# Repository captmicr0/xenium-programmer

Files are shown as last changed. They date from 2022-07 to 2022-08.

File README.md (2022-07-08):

# OpenXenium JTAG and Flash Memory programmer
New smaller size board is less wasteful and has on-board buttons that actually work with the new script!  
LEDs are connected to different GPIOs than the original board, so **the old script will not work properly**.  
Plug the RPI and the OpenXenium modchip into their respective headers, and run the new script.  
The DETECT LED below the OpenXenium outline will turn on when a modchip is inserted.

### Raspberry PI:
- This has only been tested on PI Zero W so far.

-------------
## INSTALLING THE XENIUM PROGRAMMER

On the PI:
- Clone this repo by running: `git clone https://github.com/captmicr0/xenium-programmer`
- Then run: `./install`

## UPDATING XENIUM PROGRAMMER

On the PI:
- Pull the latest code with: `git pull`
- Then run: `./install` 

-------------
## PROGRAMMING A XENIUM CPLD AND FLASH MEMORY

- Connect to the PI or Omega via SSH or Serial terminal
- Run: `./xenium-programmer-small`
- On the board, press the BIOS button to write a new BIOS to the OpenXenium flash chip
- On the board, press the CPLD button to program the Xilinx CPLD on the OpenXenium.

**Note**: Pressing the BIOS button will flash a program onto the CPLD that allows you to  
write to the flash chip. This overwrites the OpenXenium firmware, so you must re-program  
the CPLD afterwards by pressing the CPLD button.

### SMALL PC BOARD

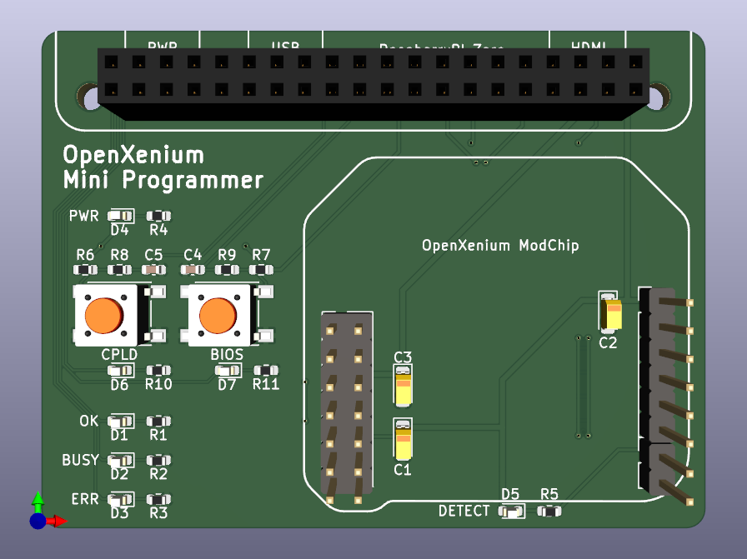
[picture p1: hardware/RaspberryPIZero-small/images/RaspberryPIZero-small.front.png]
RPI PXB


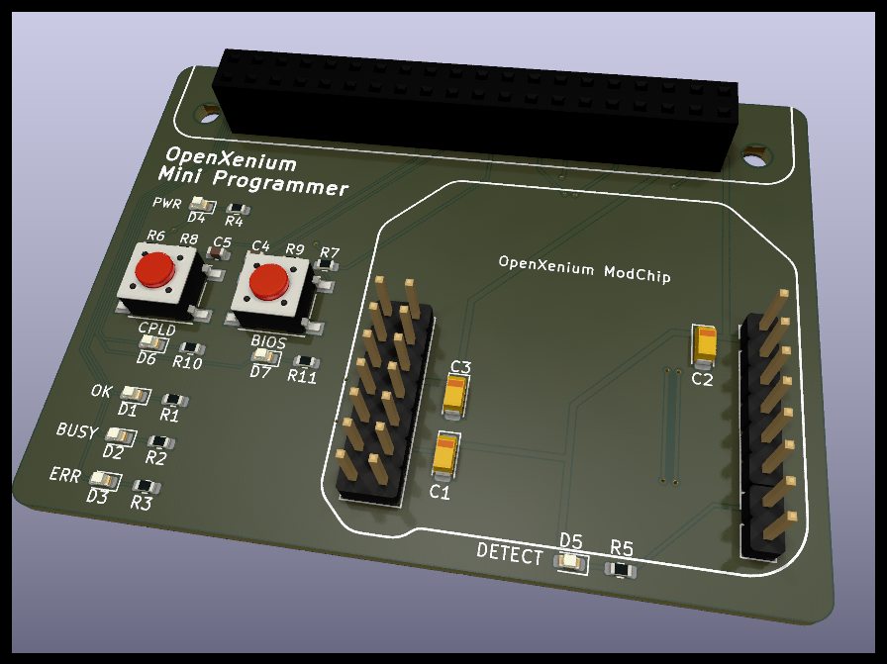
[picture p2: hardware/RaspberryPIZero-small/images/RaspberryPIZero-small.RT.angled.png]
RPI PXC


-------------
## CREDITS

- Koos du Preez - Creator (kdupreez@hotmail.com - Comments, improvements, critique, etc. is welcome!)
- James Bolding - Kick ass awesome hardware design and PCB!
- captmicr0 - Smaller board design and modified script for it.
- Ryzee119 -  OpenXenium Firmware and hardware and all round awesomeness!
- XC3SPROG - Not sure who to thank here, but the source code was pivotal in making this work!

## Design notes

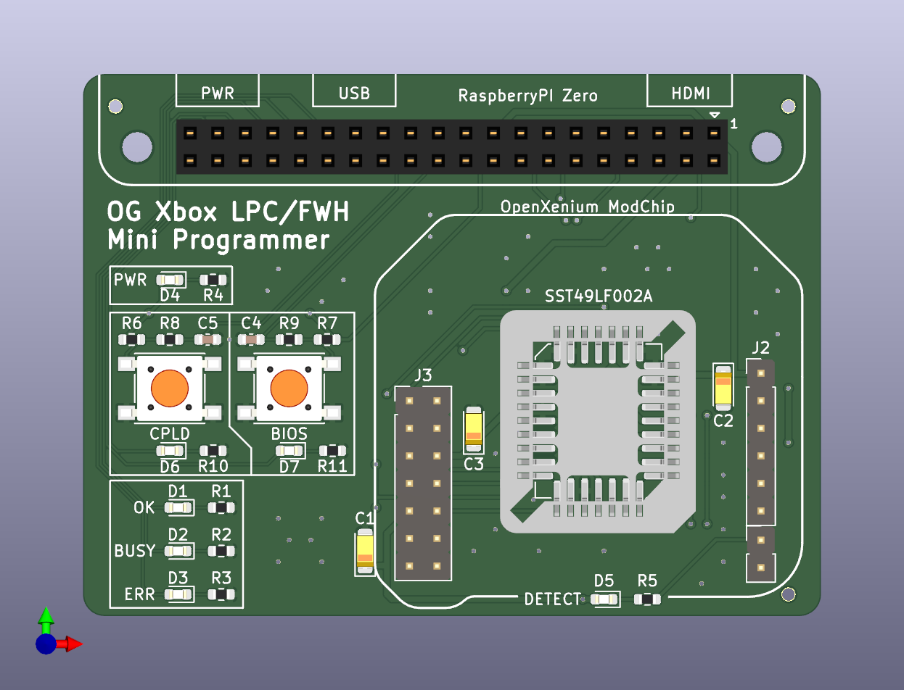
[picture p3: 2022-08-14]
hardware/RaspberryPIZero-small/images/RaspberryPIZero-small.top.png

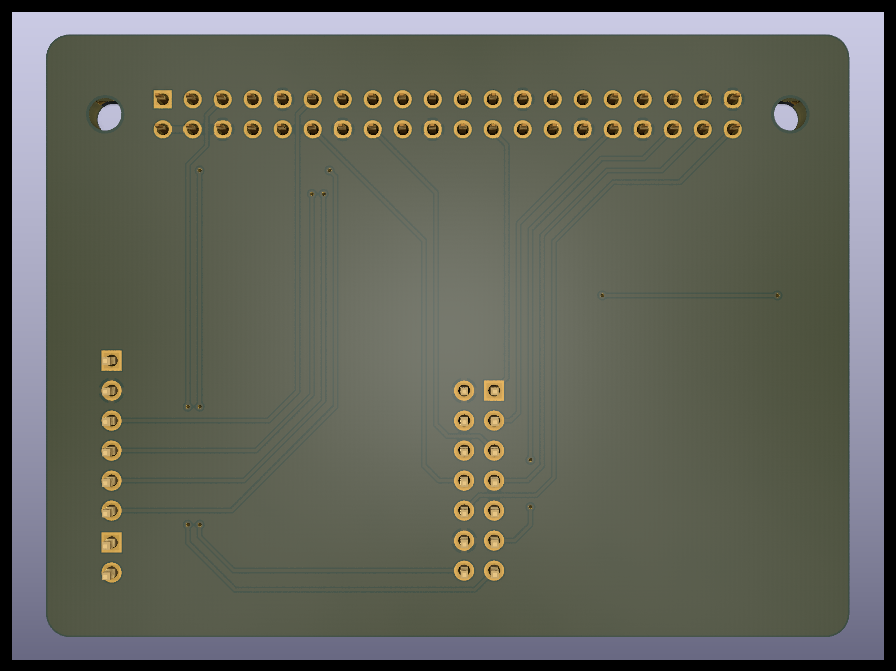
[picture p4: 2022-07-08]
hardware/RaspberryPIZero-small/images/RaspberryPIZero-small.RT.back.png

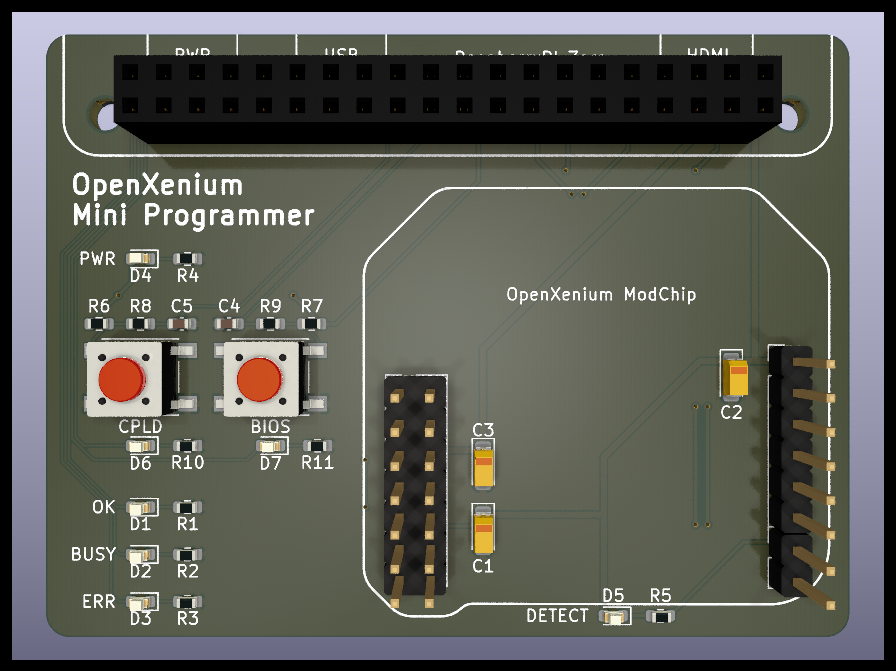
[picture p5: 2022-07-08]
hardware/RaspberryPIZero-small/images/RaspberryPIZero-small.RT.front.png

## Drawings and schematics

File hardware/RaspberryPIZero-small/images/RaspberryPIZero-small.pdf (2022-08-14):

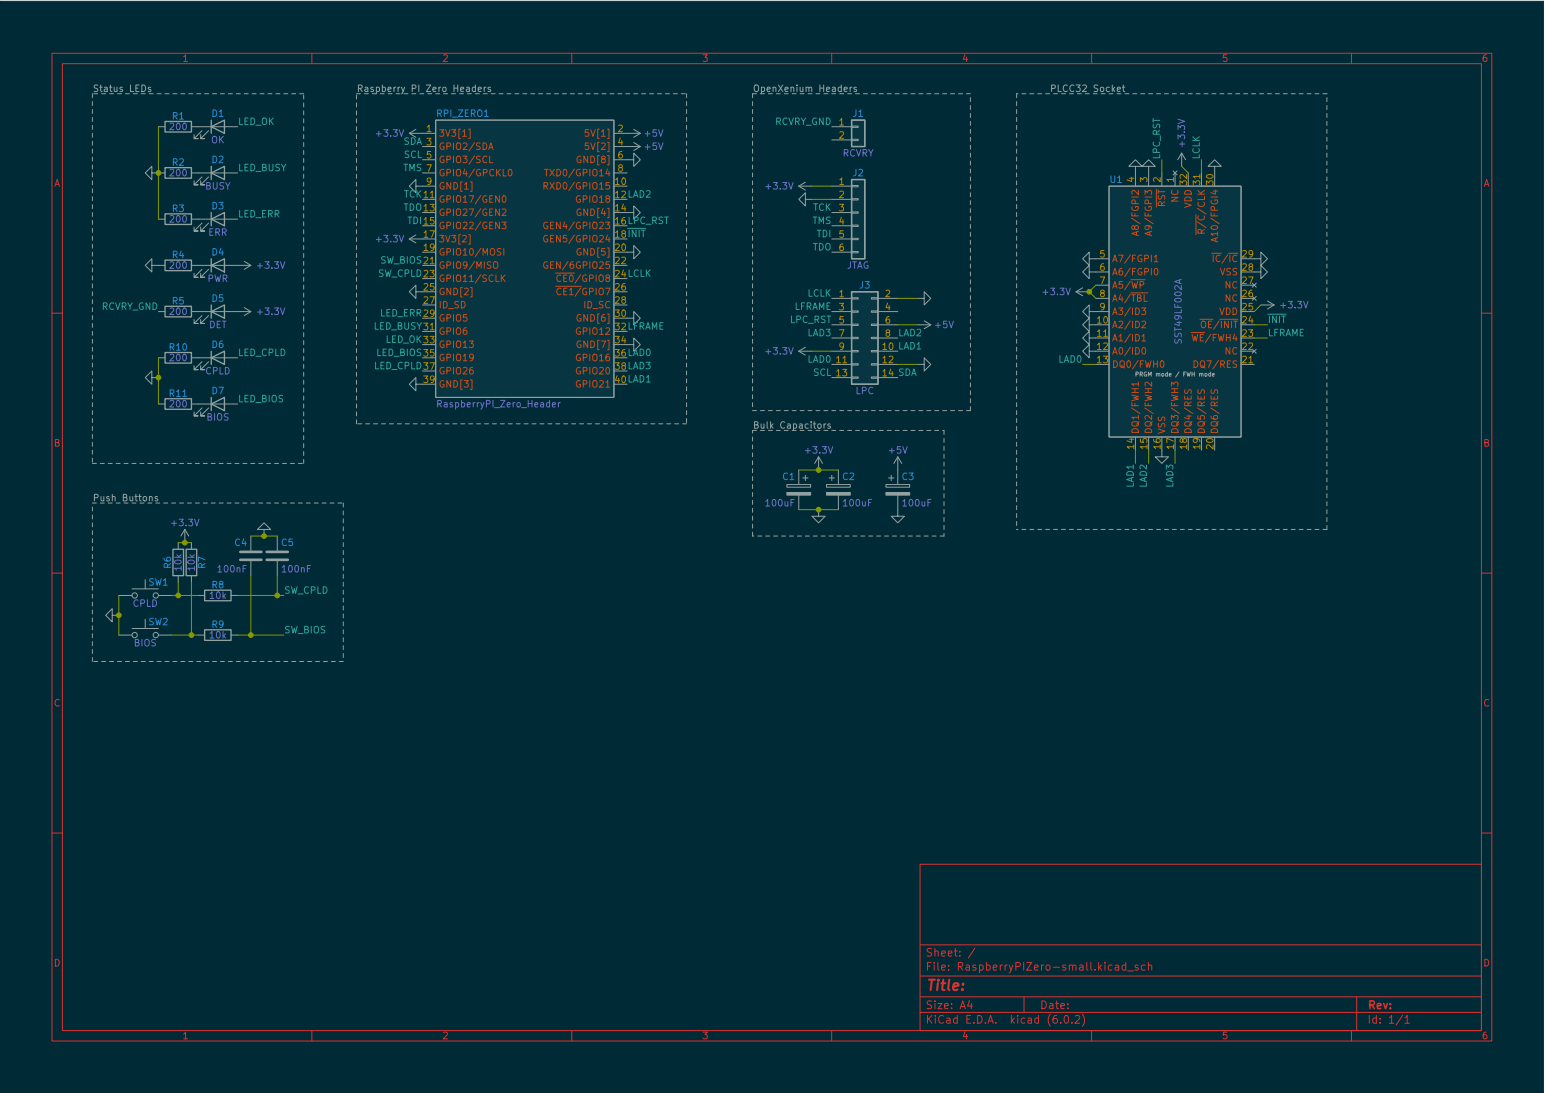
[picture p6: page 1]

PRGM mode / FWH mode NC

1 A2/ID2 10 A1/ID1 11 A0/ID0 12 DQ0/FWH0 13 DQ1/FWH1 14 DQ2/FWH2 15 VSS 16 DQ3/FWH3 17 DQ4/RES 18 DQ5/RES 19 ~{RST} 2 DQ6/RES 20 DQ7/RES 21 NC 22 ~{WE}/FWH423 ~{OE}/~{INIT}24 VDD 25 NC 26 NC 27 VSS 28 ~{IC}/~{IC}29 A9/FGPI3

File: RaspberryPIZero-small.kicad_sch Sheet: /
Id: 1/1 Title:

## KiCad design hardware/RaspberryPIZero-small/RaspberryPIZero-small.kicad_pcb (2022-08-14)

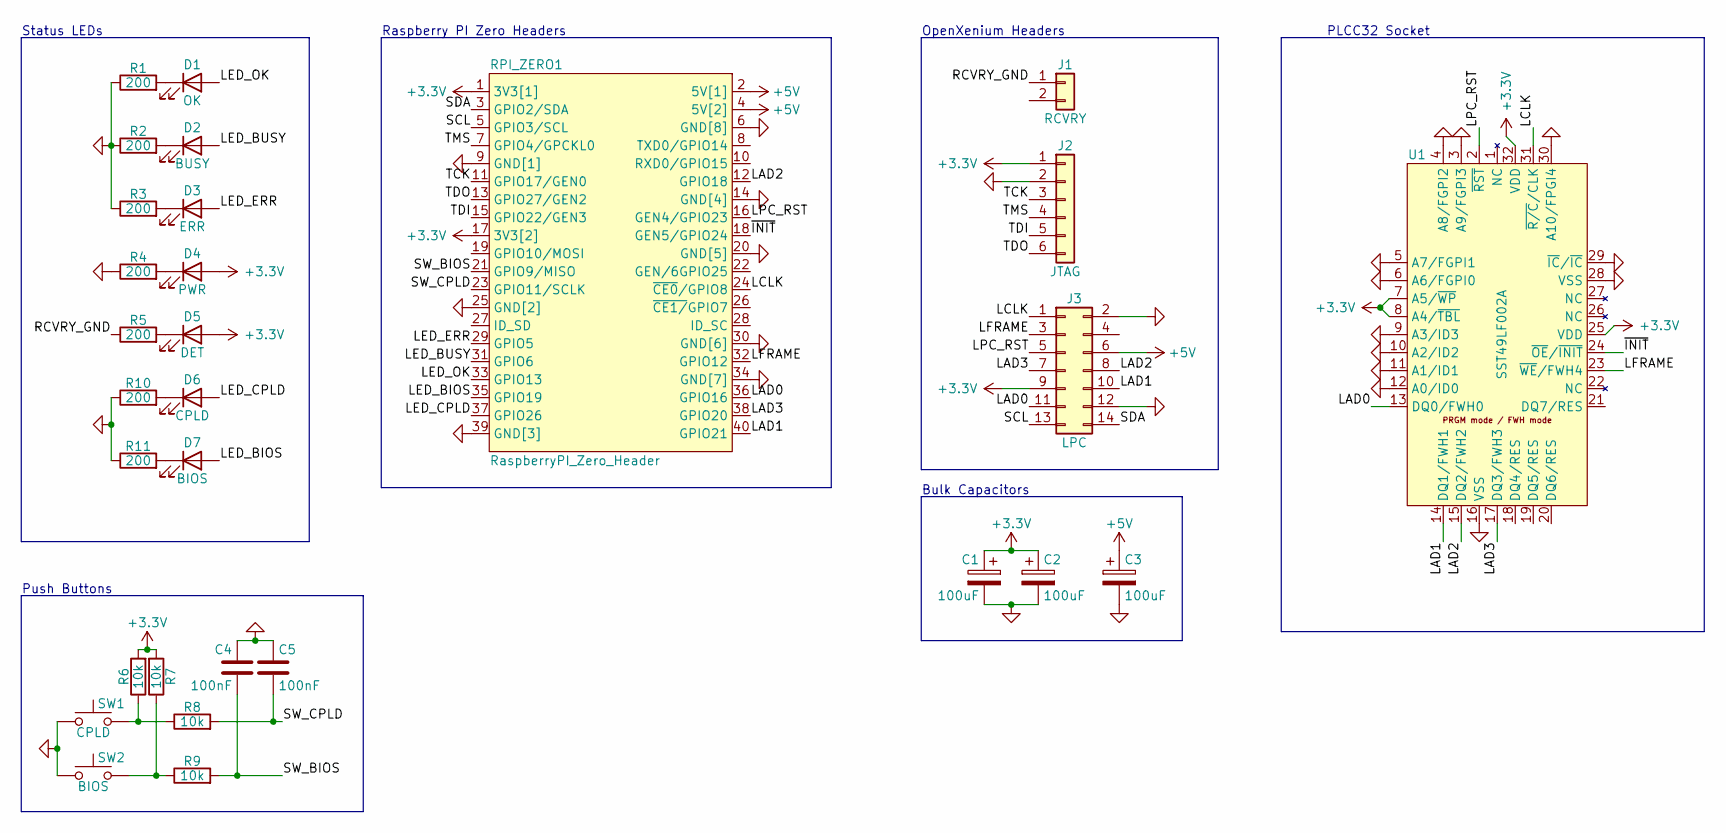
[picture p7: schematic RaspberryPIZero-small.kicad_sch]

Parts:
C1, C2, C3: 100uF; CP_EIA-3216-18_Kemet-A; MFR# CL31A107MQHNNNE; LCSC# C15008
C4, C5: 100nF; C_0603_1608Metric; MFR# CC0603KRX7R9BB104; LCSC# C14663
D1: OK; LED_0603_1608Metric; MFR# SZYY0603G; LCSC# C434420
D2: BUSY; LED_0603_1608Metric; MFR# SZYY0603O; LCSC# C434425
D3: ERR; LED_0603_1608Metric; MFR# SZYY0603R; LCSC# C434419
D4: PWR; LED_0603_1608Metric; MFR# SZYY0603B; LCSC# C434421
D5: DET; LED_0603_1608Metric; MFR# SZYY0603B; LCSC# C434421
D6: CPLD; LED_0603_1608Metric; MFR# SZYY0603O; LCSC# C434425
D7: BIOS; LED_0603_1608Metric; MFR# SZYY0603O; LCSC# C434425
J1: RCVRY; PinHeader_1x02_P2.54mm_Vertical
J2: JTAG; PinHeader_1x06_P2.54mm_Vertical; MFR# C2337; LCSC# C2337
J3: LPC; PinHeader_2x07_P2.54mm_Vertical; MFR# C57369; LCSC# C57369
R1, R2, R3, R4, R5, R10, R11: 200; R_0603_1608Metric; MFR# 0603WAF2000T5E; LCSC# C8218
R6, R7, R8, R9: 10k; R_0603_1608Metric; MFR# 0603WAF1002T5E; LCSC# C25804
RPI_ZERO1: RaspberryPI_Zero_Header; RaspberryPI_Zero; MFR# X6521FV-2x10-C85D32; LCSC# C718226
SW1: CPLD; SW_SPST_PTS645; MFR# PTS645SM70SMTR92LFS; LCSC# C221883
SW2: BIOS; SW_SPST_PTS645; MFR# PTS645SM70SMTR92LFS; LCSC# C221883
U1: SST49LF002A; PLCC-32-SOCKET-SMT

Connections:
+3V3: C1.1, C2.1, D4.2 (A), D5.2 (A), J2.1, J3.9, R6.2, R7.2, RPI_ZERO1.1 (3V3[1]), RPI_ZERO1.17 (3V3[2]), U1.7 (A5/~WP), U1.8 (A4/~TBL), U1.25 (VDD), U1.32 (VDD)
+5V: C3.1, J3.6, RPI_ZERO1.2 (5V[1]), RPI_ZERO1.4 (5V[2])
/LAD0: J3.11, RPI_ZERO1.36 (GPIO16), U1.13 (DQ0/FWH0)
/LAD1: J3.10, RPI_ZERO1.40 (GPIO21), U1.14 (DQ1/FWH1)
/LAD2: J3.8, RPI_ZERO1.12 (GPIO18), U1.15 (DQ2/FWH2)
/LAD3: J3.7, RPI_ZERO1.38 (GPIO20), U1.17 (DQ3/FWH3)
/LCLK: J3.1, RPI_ZERO1.24 (~CE0/GPIO8), U1.31 (~R/C/CLK)
/LED_BIOS: D7.2 (A), RPI_ZERO1.35 (GPIO19)
/LED_BUSY: D2.2 (A), RPI_ZERO1.31 (GPIO6)
/LED_CPLD: D6.2 (A), RPI_ZERO1.37 (GPIO26)
/LED_ERR: D3.2 (A), RPI_ZERO1.29 (GPIO5)
/LED_OK: D1.2 (A), RPI_ZERO1.33 (GPIO13)
/LFRAME: J3.3, RPI_ZERO1.32 (GPIO12), U1.23 (~WE/FWH4)
/LPC_RST: J3.5, RPI_ZERO1.16 (GEN4/GPIO23), U1.2 (~RST)
/RCVRY_GND: J1.1, R5.1
/SCL: J3.13, RPI_ZERO1.5 (GPIO3/SCL)
/SDA: J3.14, RPI_ZERO1.3 (GPIO2/SDA)
/SW_BIOS: C4.2, R9.2, RPI_ZERO1.21 (GPIO9/MISO)
/SW_CPLD: C5.2, R8.2, RPI_ZERO1.23 (GPIO11/SCLK)
/TCK: J2.3, RPI_ZERO1.11 (GPIO17/GEN0)
/TDI: J2.5, RPI_ZERO1.15 (GPIO22/GEN3)
/TDO: J2.6, RPI_ZERO1.13 (GPIO27/GEN2)
/TMS: J2.4, RPI_ZERO1.7 (GPIO4/GPCKL0)
/~INIT: RPI_ZERO1.18 (GEN5/GPIO24), U1.24 (~OE/~INIT)
GND: C1.2, C2.2, C3.2, C4.1, C5.1, J2.2, J3.2, J3.12, R1.1, R2.1, R3.1, R4.1, R10.1, R11.1, RPI_ZERO1.6 (GND[8]), RPI_ZERO1.9 (GND[1]), RPI_ZERO1.14 (GND[4]), RPI_ZERO1.20 (GND[5]), RPI_ZERO1.25 (GND[2]), RPI_ZERO1.30 (GND[6]), RPI_ZERO1.34 (GND[7]), RPI_ZERO1.39 (GND[3]), SW1.1, SW2.1, U1.3 (A9/FGPI3), U1.4 (A8/FGPI2), U1.5 (A7/FGPI1), U1.6 (A6/FGPI0), U1.9 (A3/ID3), U1.10 (A2/ID2), U1.11 (A1/ID1), U1.12 (A0/ID0), U1.16 (VSS), U1.28 (VSS), U1.29 (~IC/~IC), U1.30 (A10/FPGI4)
unnamed: D1.1 (K), R1.2
unnamed: D2.1 (K), R2.2
unnamed: D3.1 (K), R3.2
unnamed: D4.1 (K), R4.2
unnamed: D5.1 (K), R5.2
unnamed: D6.1 (K), R10.2
unnamed: D7.1 (K), R11.2
unnamed: R6.1, R8.1, SW1.2
unnamed: R7.1, R9.1, SW2.2

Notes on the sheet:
OpenXenium Headers
Bulk Capacitors
PLCC32 Socket
Status LEDs
Push Buttons
Raspberry PI Zero Headers

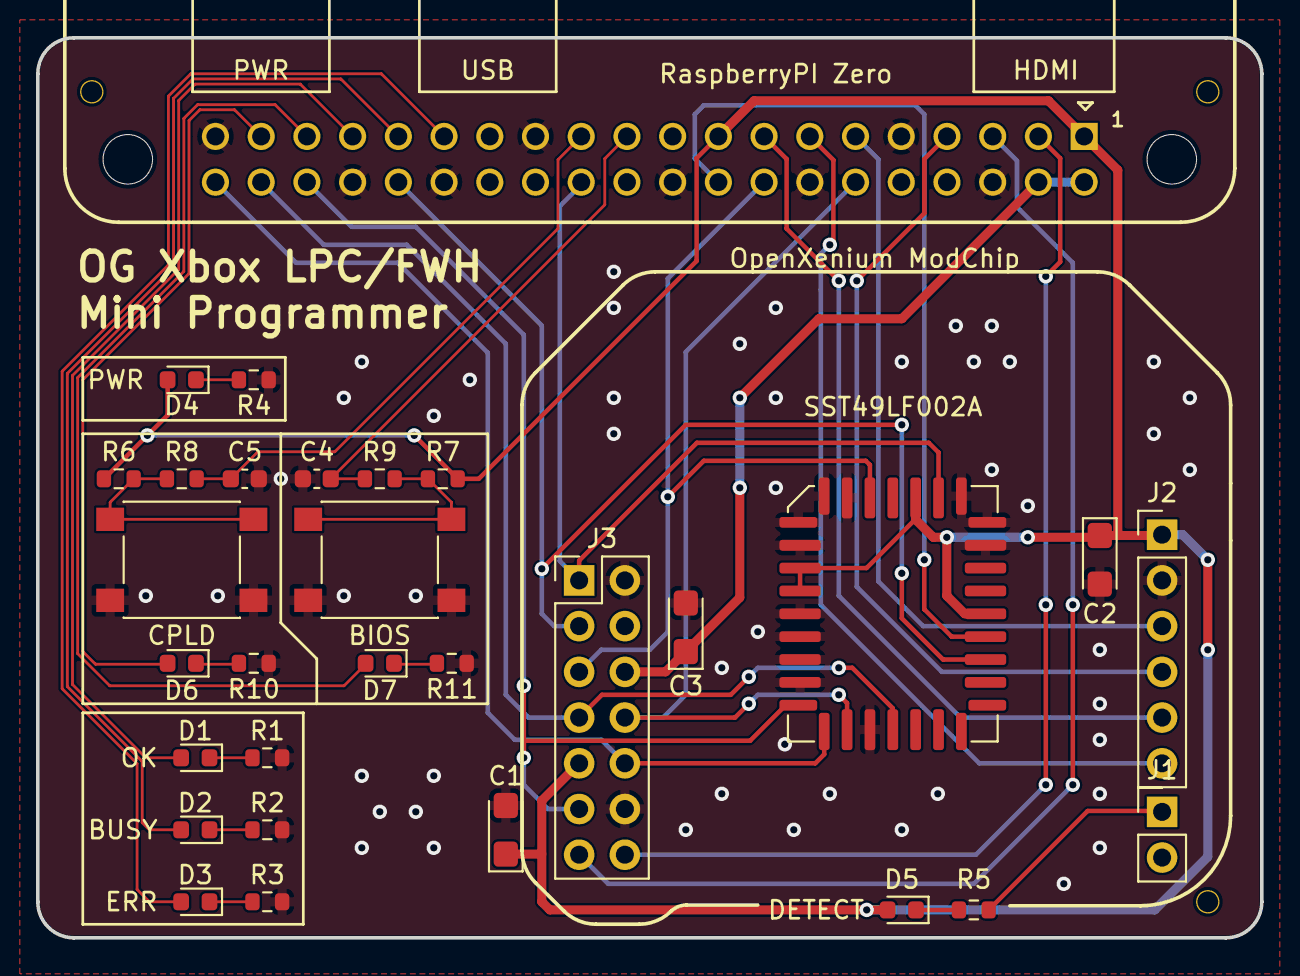
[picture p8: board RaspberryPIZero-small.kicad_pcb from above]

Board: 2 copper layers, 68.0 x 50.0 mm, 30 parts (0 on the bottom side), 34 nets.

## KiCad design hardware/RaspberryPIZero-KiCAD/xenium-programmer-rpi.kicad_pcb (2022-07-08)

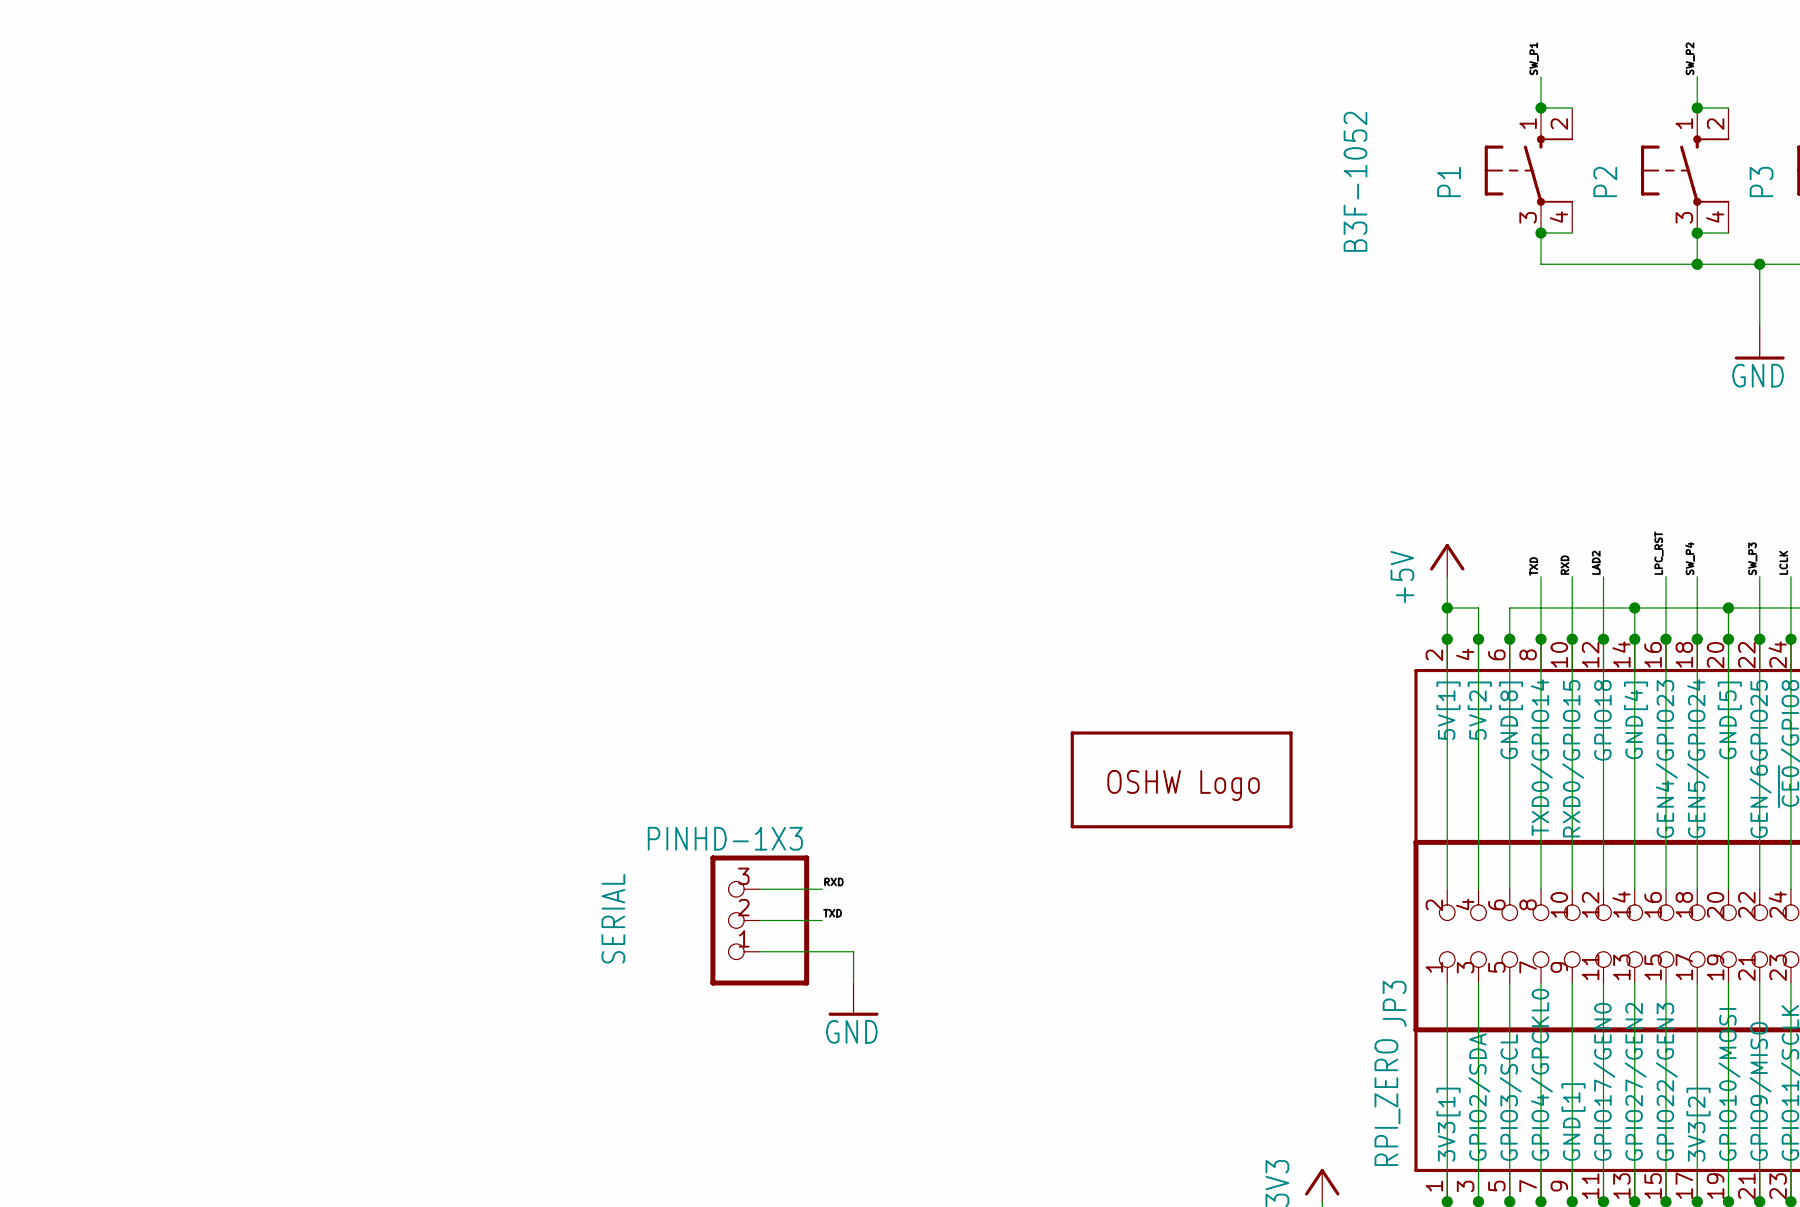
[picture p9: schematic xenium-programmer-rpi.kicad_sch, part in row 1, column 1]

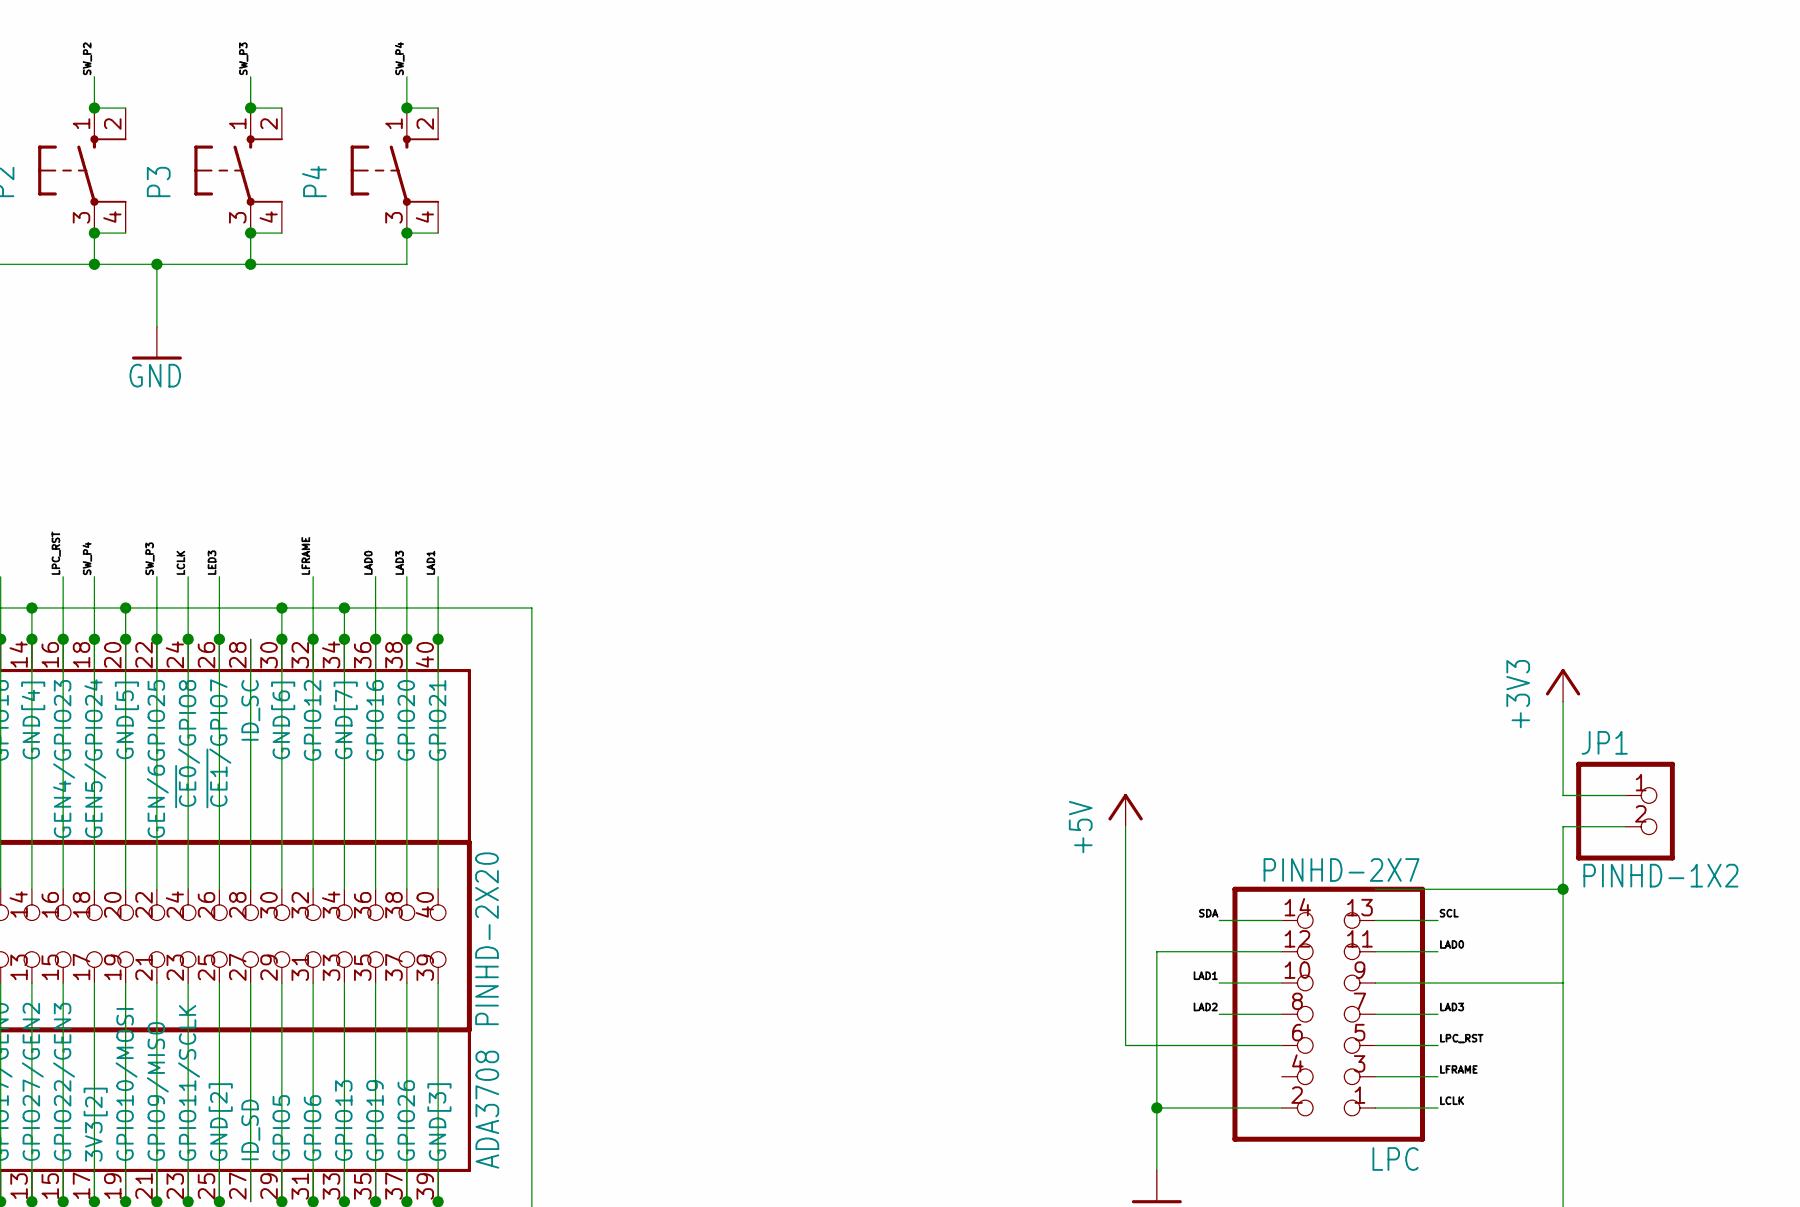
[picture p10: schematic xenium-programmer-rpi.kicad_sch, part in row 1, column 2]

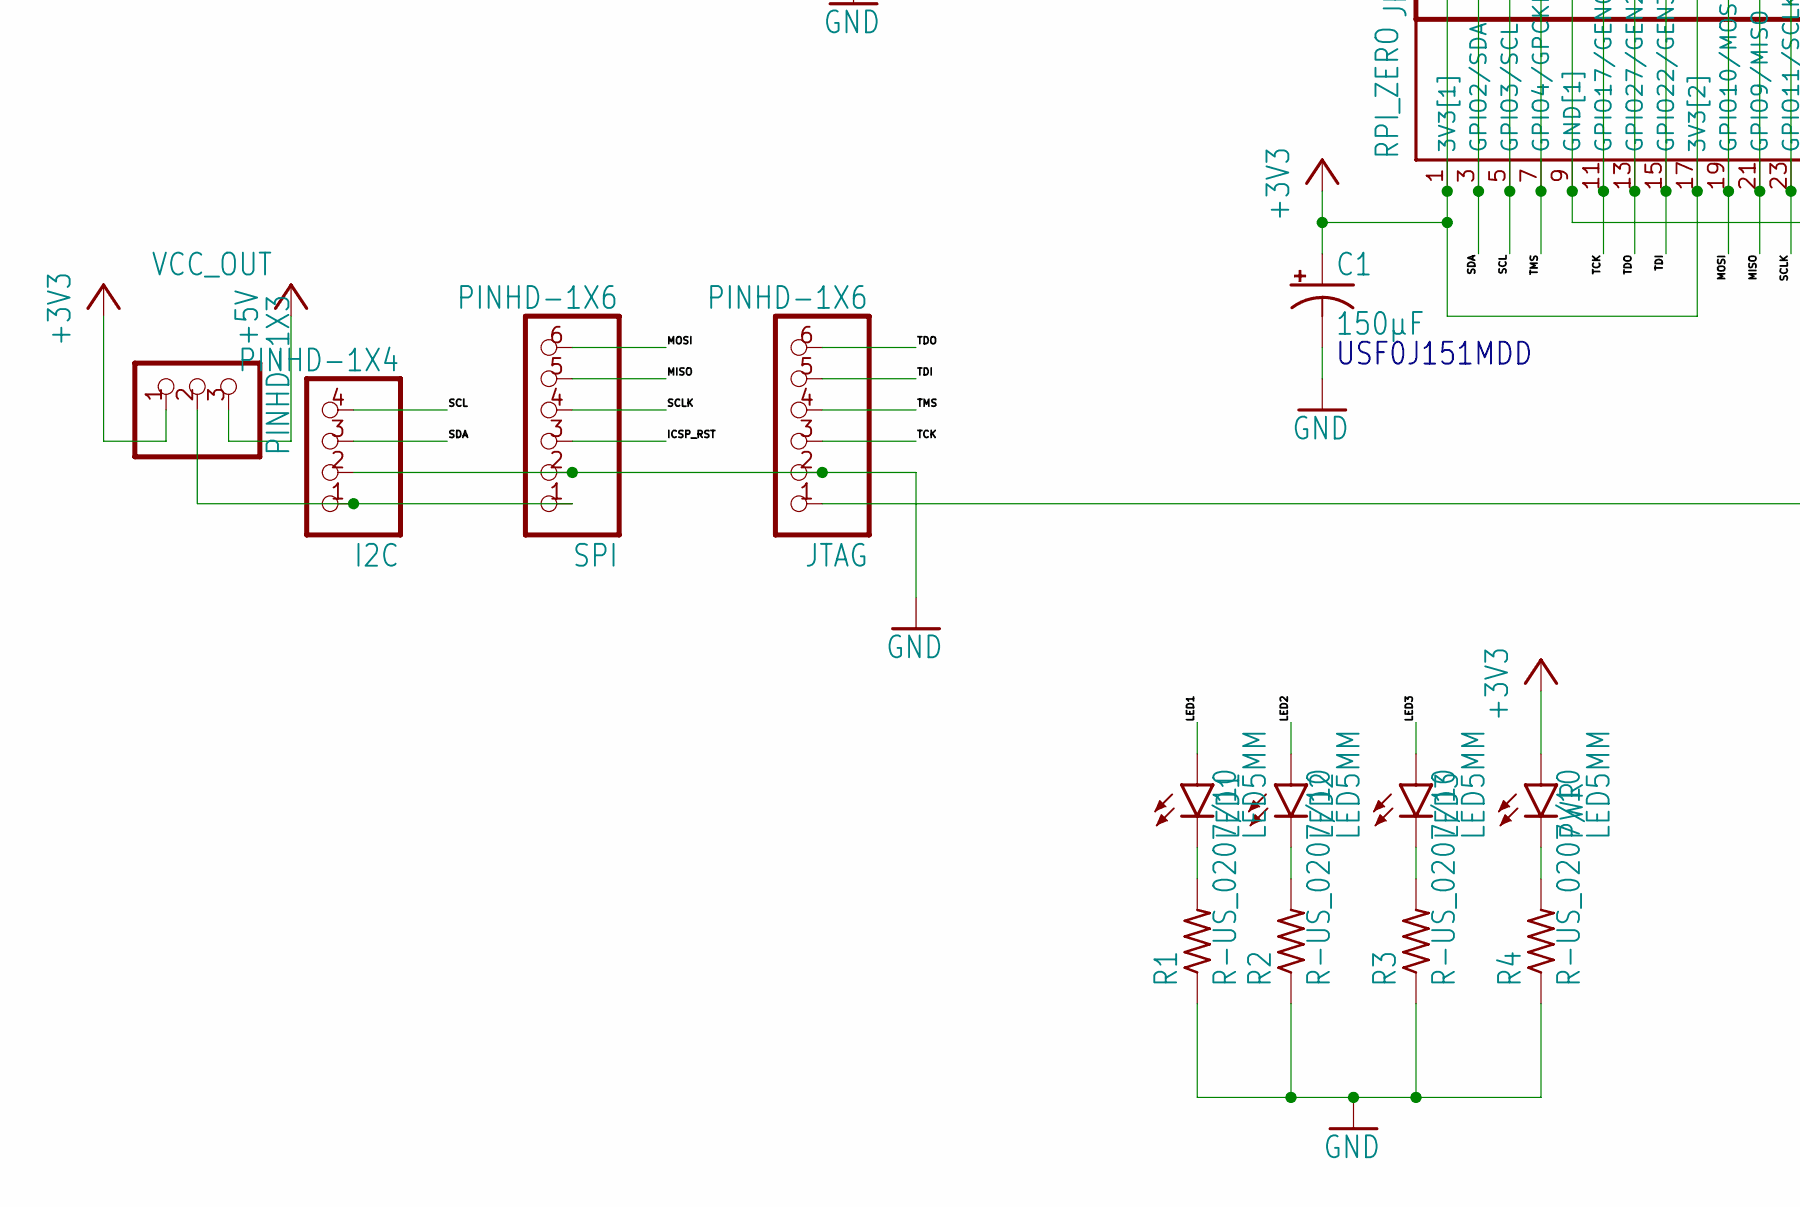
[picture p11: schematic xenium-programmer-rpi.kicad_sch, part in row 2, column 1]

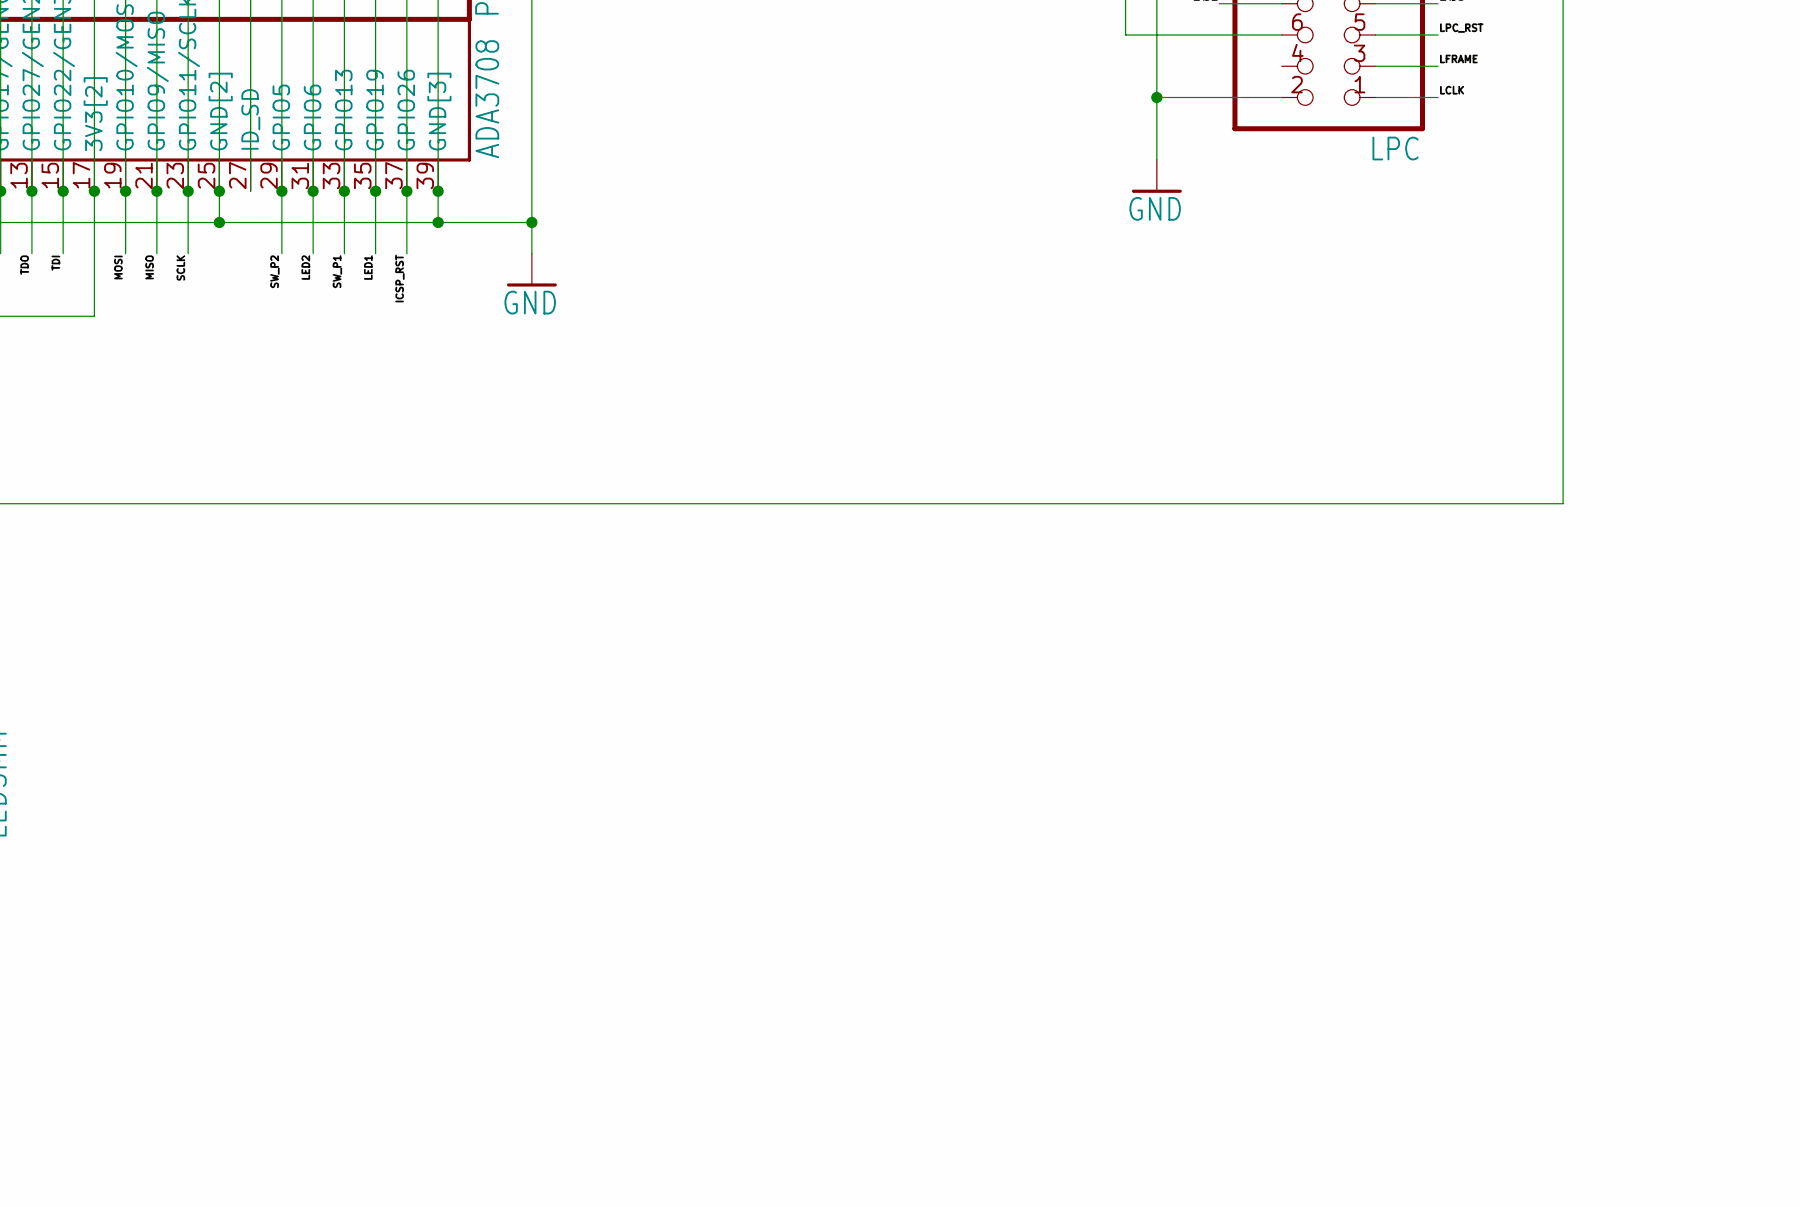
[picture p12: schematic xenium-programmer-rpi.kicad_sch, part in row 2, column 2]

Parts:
C1: 150µF; E3,5-8
GOLD_ORB_SM1: OSHWLOGOLOGO8MM; OSHW_8MM
I2C: PINHD-1X4; 1X04
JP1: PINHD-1X2; 1X02
JP3: PINHD-2X20; 2X20
JTAG: PINHD-1X6; 1X06
LED1, LED2, LED3: LED5MM
LPC: PINHD-2X7; 2X07
P1, P2, P3, P4: B3F-1052; B3F-10XX
PWR: LED5MM
R1, R2, R3, R4: R-US_0207/10; 0207_10
RPI_ZERO: ADA3708; ADA3708_RPI-ZERO
SERIAL: PINHD-1X3; 1X03
SPI: PINHD-1X6; 1X06
VCC_OUT: PINHD-1X3; 1X03

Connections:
+3V3: C1.+, JP1.1, JP3.1, JP3.17, PWR.A, RPI_ZERO.1 (3V3[1]), RPI_ZERO.17 (3V3[2]), VCC_OUT.1
+5V: JP3.2, JP3.4, LPC.6, RPI_ZERO.2 (5V[1]), RPI_ZERO.4 (5V[2]), VCC_OUT.3
GND: C1.-, I2C.2, JP3.6, JP3.9, JP3.14, JP3.20, JP3.25, JP3.30, JP3.34, JP3.39, JTAG.2, LPC.2, LPC.12, P1.3, P1.4 (P1), P2.3, P2.4 (P1), P3.3, P3.4 (P1), P4.3, P4.4 (P1), R1.1, R2.1, R3.1, R4.1, RPI_ZERO.6 (GND[8]), RPI_ZERO.9 (GND[1]), RPI_ZERO.14 (GND[4]), RPI_ZERO.20 (GND[5]), RPI_ZERO.25 (GND[2]), RPI_ZERO.30 (GND[6]), RPI_ZERO.34 (GND[7]), RPI_ZERO.39 (GND[3]), SERIAL.1, SPI.2
ICSP_RST: JP3.37, RPI_ZERO.37 (GPIO26), SPI.3
LAD0: JP3.36, LPC.11, RPI_ZERO.36 (GPIO16)
LAD1: JP3.40, LPC.10, RPI_ZERO.40 (GPIO21)
LAD2: JP3.12, LPC.8, RPI_ZERO.12 (GPIO18)
LAD3: JP3.38, LPC.7, RPI_ZERO.38 (GPIO20)
LCLK: JP3.24, LPC.1, RPI_ZERO.24 (~CE0/GPIO8)
LED1: JP3.35, LED1.A, RPI_ZERO.35 (GPIO19)
LED2: JP3.31, LED2.A, RPI_ZERO.31 (GPIO6)
LED3: JP3.26, LED3.A, RPI_ZERO.26 (~CE1/GPIO7)
LFRAME: JP3.32, LPC.3, RPI_ZERO.32 (GPIO12)
LPC_RST: JP3.16, LPC.5, RPI_ZERO.16 (GEN4/GPIO23)
MISO: JP3.21, RPI_ZERO.21 (GPIO9/MISO), SPI.5
MOSI: JP3.19, RPI_ZERO.19 (GPIO10/MOSI), SPI.6
unnamed: LED1.K (C), R1.2
unnamed: JP3.27, RPI_ZERO.27 (ID_SD)
unnamed: LED2.K (C), R2.2
unnamed: LED3.K (C), R3.2
unnamed: PWR.K (C), R4.2
unnamed: JP1.2, JTAG.1, LPC.9
unnamed: JP3.28, RPI_ZERO.28 (ID_SC)
RXD: JP3.10, RPI_ZERO.10 (RXD0/GPIO15), SERIAL.3
SCL: I2C.4, JP3.5, LPC.13, RPI_ZERO.5 (GPIO3/SCL)
SCLK: JP3.23, RPI_ZERO.23 (GPIO11/SCLK), SPI.4
SDA: I2C.3, JP3.3, LPC.14, RPI_ZERO.3 (GPIO2/SDA)
SW_P1: JP3.33, P1.1 (S), P1.2 (S1), RPI_ZERO.33 (GPIO13)
SW_P2: JP3.29, P2.1 (S), P2.2 (S1), RPI_ZERO.29 (GPIO5)
SW_P3: JP3.22, P3.1 (S), P3.2 (S1), RPI_ZERO.22 (GEN/6GPIO25)
SW_P4: JP3.18, P4.1 (S), P4.2 (S1), RPI_ZERO.18 (GEN5/GPIO24)
TCK: JP3.11, JTAG.3, RPI_ZERO.11 (GPIO17/GEN0)
TDI: JP3.15, JTAG.5, RPI_ZERO.15 (GPIO22/GEN3)
TDO: JP3.13, JTAG.6, RPI_ZERO.13 (GPIO27/GEN2)
TMS: JP3.7, JTAG.4, RPI_ZERO.7 (GPIO4/GPCKL0)
TXD: JP3.8, RPI_ZERO.8 (TXD0/GPIO14), SERIAL.2
VCC_OUT: I2C.1, SPI.1, VCC_OUT.2

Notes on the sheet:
USF0J151MDD

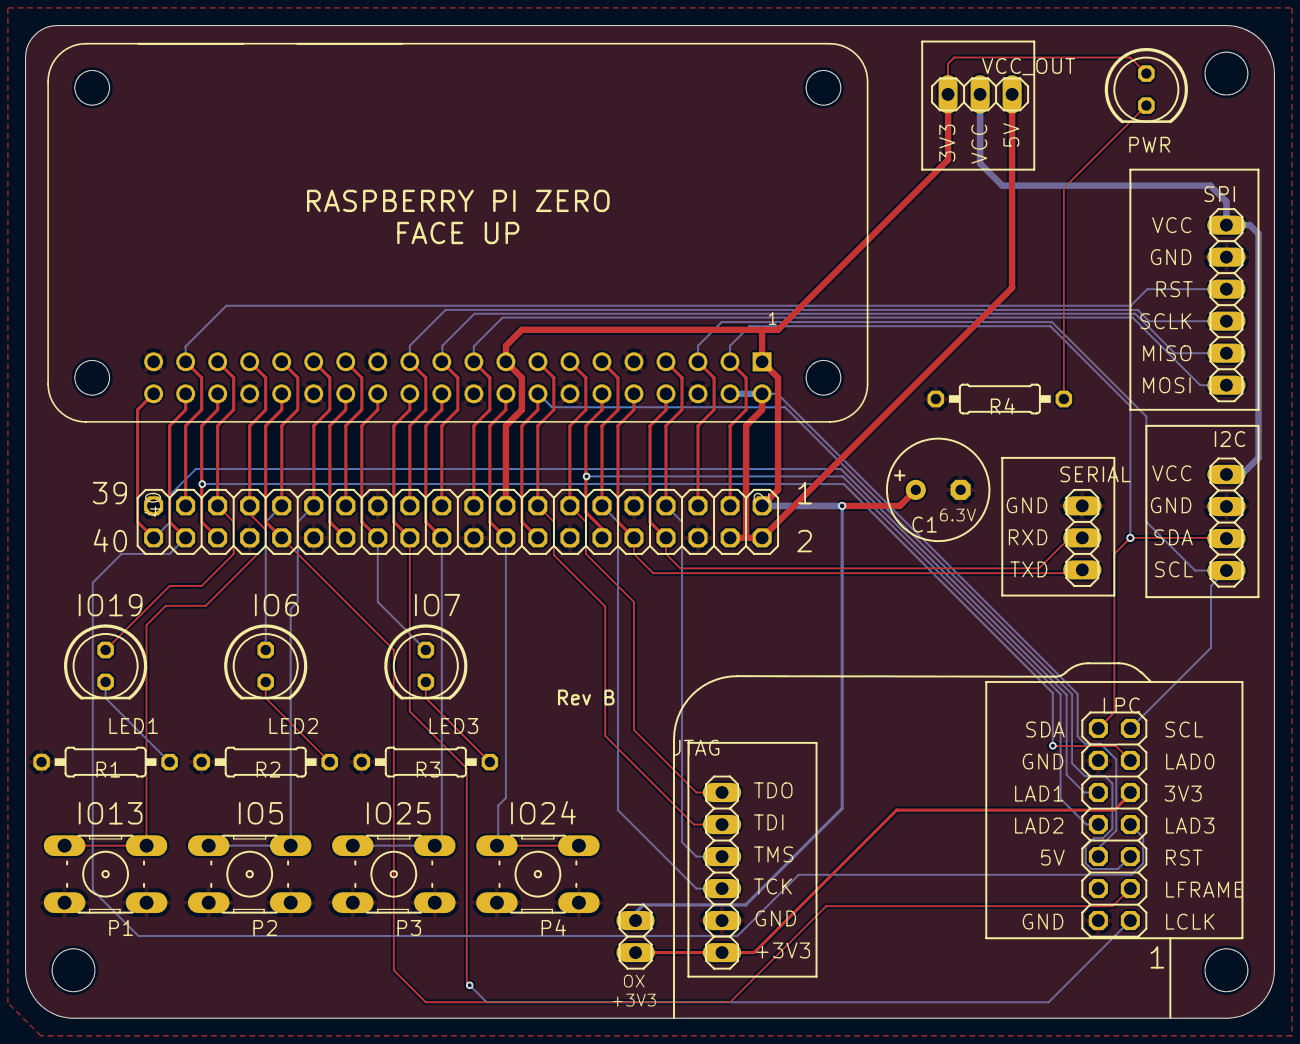
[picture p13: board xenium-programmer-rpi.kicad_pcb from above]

Board: 2 copper layers, 99.1 x 78.7 mm, 26 parts (1 on the bottom side), 37 nets.

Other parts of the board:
@HOLE0, @HOLE1, @HOLE2: (no value)

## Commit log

2022-07-08 converted to KiCAD, added SFF board, added script for SFF board
    [RaspberryPIZero-small-B_Cu.gbl, RaspberryPIZero-small-B_Mask.gbs, RaspberryPIZero-small-B_Paste.gbp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]
2022-07-08 added tooling holes to pcb & create JLCPCB manufacturing files
    [RaspberryPIZero-small-B_Cu.gbl, RaspberryPIZero-small-B_Mask.gbs, RaspberryPIZero-small-B_Paste.gbp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]
2022-08-14 modified board to support flashing 49LF002A
    [RaspberryPIZero-small-B_Cu.gbl, RaspberryPIZero-small-B_Mask.gbs, RaspberryPIZero-small-B_Paste.gbp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]

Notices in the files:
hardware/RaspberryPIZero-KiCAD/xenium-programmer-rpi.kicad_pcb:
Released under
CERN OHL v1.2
